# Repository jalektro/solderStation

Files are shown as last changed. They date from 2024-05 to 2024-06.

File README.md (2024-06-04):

First big schoolproject : SolderStation that is powered bij a battery(makita 18V)

In the files you can find all the schematics of the main board. There is a connection for a makita battery what can connect directly on makita 644808-8 terminal.

the display is external and is powered by a cable between display PCB and main PCB. 

the GX12 pin for soldering is wired as follows : 
-  Pin1 power from common mode choke CM2545X171B-10
-  Pin2 ground from common mode choke CM2545X171B-10
-  Pin3 output OP-AMP for temperature 
-  Pin4 connected to ground 

There are some issues in the schematics that needs to be fixed. 
The OP-AMP MCP6002-I/P VSS(pin4) and VCC(pin8)  are switched this is fixed in the schematics but not on PCB
The C-pin  of the rotary encoder PEC11R-4220F-S0012  switch is nog connected to gorund. Fixed on schematic but not on PCB

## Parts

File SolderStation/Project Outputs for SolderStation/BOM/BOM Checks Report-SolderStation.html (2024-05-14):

Date: |  | 18/04/2024
Time: |  | 18:44
Elapsed Time: |  | 00:00:00
Filename: |  | C:\AltiumFiles\SolderStation\SolderStation.BomDoc
Warnings: |  | 0
Errors: |  | 0
Fatal Errors: |  | 70
Warnings: | Count
Total | 0
Errors: | Count
Total | 0
Fatal Errors: | Count
No solutions | 70
Total | 70
No solutions
C1 , C2, C3, C4, C5, C6, C7, C8, C9, C10, C11, C17, C18, CN1, CN2, CN3, CN4, CN5, CN6, D1, D2, F1, IC1, IC2, J1, J2, J3, J4, J5, J6, J7, J8, K1, L1, L2, MAK1, R1, R2, R3, R4, R5, R6, R7, R8, R9, R10, R11, R12, R13, R14, R15, R16, R17, R18, R22, R23, R24, R25, T1, T2, T3, T4, T5, TP1, TP2, TP3, TP4, TP5, U2, ZD1

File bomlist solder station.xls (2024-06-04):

 | SOLDER STATION
Bought | Mouser No | Mfr. No | Manufacturer | Description | Qty. | Price | Total Price
Mouser | 80-C0805C103K5RAC | C0805C103K5RAC | KEMET | Multilayer Ceramic Capacitors MLCC - SMD/SMT 50V 0.01uF X7R 0805 10% | 9 | €0.03 | €0.29
Mouser | 80-C0805C104M5RACTM | C0805C104M5RAC7025 | KEMET | Multilayer Ceramic Capacitors MLCC - SMD/SMT 50V 0.1uF X7R 0805 20% | 4 | €0.02 | €0.09
Mouser | 581-TAP106M050BRW | TAP106M050BRW | KYOCERA AVX | Tantalum Capacitors - Solid Leaded 50V 10uF 20% ESR=1.6 Ohm | 3 | €2.16 | €6.48
Mouser | 581-TAP107K020CCS | TAP107K020CCS | KYOCERA AVX | Tantalum Capacitors - Solid Leaded 20V 100uF Radial ESR=600mOhms 10% | 2 | €1.65 | €3.30
Mouser | 652-PEC11R-4320K-S12 | PEC11R-4320K-S0012 | Bourns | Encoders ENCODER | 1 | €1.79 | €1.79
Mouser | 571-1033081 | 103308-1 | TE Connectivity | Headers & Wire Housings HDR VERT DOUBLE 10P low profile | 2 | €2.06 | €4.12
Mouser | 571-1658620-1 | 1658620-1 | TE Connectivity | Headers & Wire Housings MLTRY PLRZD RECPT 10 NOVO | 2 | €1.02 | €2.04
Mouser | 617-09180107001 | 09180107001 | HARTING | Flat Cables SEK CAB FLAT STD | 1 | €0.77 | €0.77
Mouser | 556-ATMEGA4809-PF | ATMEGA4809-PF | Microchip | 8-bit Microcontrollers - MCU 20MHz, 48KB, PDIP40, Ind 125C, Green | 1 | €2.88 | €2.88
Mouser | 737-ICS-640-T | ICS-640-T | Adam Tech | IC & Component Sockets 40P / .600" | 1 | €0.35 | €0.35
Mouser | 737-ICS-320-T | ICS-320-T | Adam Tech | IC & Component Sockets 20P / .300" | 1 | €0.20 | €0.20
Mouser | 576-0154003.DR | 0154003.DR | Littelfuse | Surface Mount Fuses Fuseblock w/ fuse 3A OMNI BLOK 154 | 1 | €2.08 | €2.08
Mouser | 579-MCP6002-I/P | MCP6002-I/P | Microchip | Operational Amplifiers - Op Amps Dual 1.8V 1MHz | 1 | €0.41 | €0.41
Mouser | 571-1-2199298-2 | 1-2199298-2 | TE Connectivity | IC & Component Sockets 8P DIP SKT 300 CL LADDER | 1 | €0.24 | €0.24
Mouser | 538-90151-2106 | 90151-2106 | Molex | Headers & Wire Housings C-GRID PCB CONN DR VT TN-A 6CKT | 1 | €3.02 | €3.02
Mouser | 653-G6S-2F-DC5 | G6S-2F-DC5 | Omron | Low Signal Relays - PCB Gullwing NonLatching DPDT 5VDC 140mW | 1 | €3.77 | €3.77
Mouser | 710-74479887310A | 74479887310A | Wurth Elektronik | Power Inductors - SMD WE-PMI 1008 10uH 850mA 300mOhms | 1 | €1.18 | €1.18
Mouser | 875-CM2545X171B-10 | CM2545X171B-10 | Laird Performance Materials | Common Mode Chokes / Filters 170ohms 100MHz 10A 1 Choke Thru-hole | 1 | €1.82 | €1.82
Mouser | 512-BC547B | BC547B | onsemi | Bipolar Transistors - BJT NPN 45V 100mA | 3 | €0.29 | €0.88
Mouser | 512-BC557BTF | BC557BTF | onsemi | Bipolar Transistors - BJT PNP Si Transistor Epitaxial | 1 | €0.20 | €0.20
Mouser | 844-IRF9Z34SPBF | IRF9Z34SPBF | Vishay | MOSFET P-Chan 60V 18 Amp | 1 | €1.58 | €1.58
Mouser | 595-LM7805SX/NOPB | LM7805SX/NOPB | Texas Instruments | Linear Voltage Regulators 1.5-A, 30-V, linear voltage regulator 3-DDPAK/TO-263 0 to 125 | 1 | €1.74 | €1.74
Mouser | 78-TZX5V1B | TZX5V1B-TR | Vishay | Zener Diodes 5.1 Volt 0.5W 5% | 1 | €0.11 | €0.11
Mouser | 603-AC0805FR-13100RL | AC0805FR-13100RL | YAGEO | Thick Film Resistors - SMD 100 Ohms 1/8 Wa 0805 1% AEC-Q200 | 3 | €0.01 | €0.04
Mouser | 603-AC0805FR-1010ML | AC0805FR-1010ML | YAGEO | Thick Film Resistors - SMD 10 MOhms 1/8 Watt 0805 1% AEC-Q200 | 1 | €0.01 | €0.01
Mouser | 603-AC0805FR-0710KL | AC0805FR-0710KL | YAGEO | Thick Film Resistors - SMD 10 kOhms 125mW 0805 1% AEC-Q200 Standard Power Version | 6 | €0.01 | €0.07
Mouser | 603-AC0805FR-071ML | AC0805FR-071ML | YAGEO | Thick Film Resistors - SMD 1 MOhms 125 mW 0805 1% AEC-Q200 Standard Power Version | 1 | €0.01 | €0.01
Mouser | 603-AC0805FR-075K6L | AC0805FR-075K6L | YAGEO | Thick Film Resistors - SMD 5.6k Ohms 1/8W 0805 1% AEC-Q200 Standard Power Version | 4 | €0.01 | €0.04
Mouser | 603-AC0805FR-074K7L | AC0805FR-074K7L | YAGEO | Thick Film Resistors - SMD 4.7 kOhms 125mW 0805 1% AEC-Q200 Standard Power Version | 6 | €0.01 | €0.07
Mouser | 603-AC0805FR-0718KL | AC0805FR-0718KL | YAGEO | Thick Film Resistors - SMD 18 k Ohms 125mW 0805 1% AEC-Q200 Standard Power Version | 3 | €0.02 | €0.06
Mouser | 603-AC0805FR-076K8L | AC0805FR-076K8L | YAGEO | Thick Film Resistors - SMD 6.8k Ohms 1/2W 1210 1% C-Q200 Standard Power Version | 1 | €0.01 | €0.01
Aliexpress |  |  |  | headers full set | 1 | €6.65 | €6.65
Amazon |  |  |  | connector for soldering iron GX12 4pin | 1 | €2.00 | €2.00
Aliexpress |  |  |  | DC-DC step down convertor | 1 | €4.13 | €4.13
Aliexpress |  |  |  | TM1637 Dip-20 IC | 1 | €0.40 | €0.40
TME |  |  |  | 7seg display | 1 | €1.70 | €1.70
 |  |  |  |  |  | Total price | €54.53

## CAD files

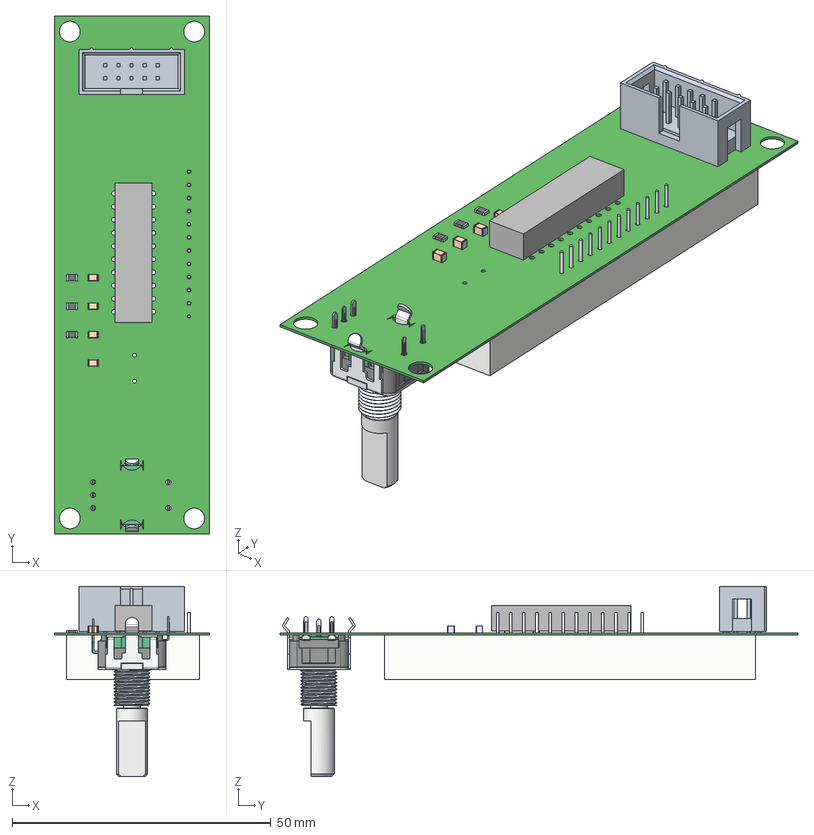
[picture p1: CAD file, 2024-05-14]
DisplaySolderStation/Display.step
30.0 x 100.0 x 36.7 mm
term1 x 3
term2 x 3
7segment v1
c-1634688-10-c-3d
Extruded
Bourns

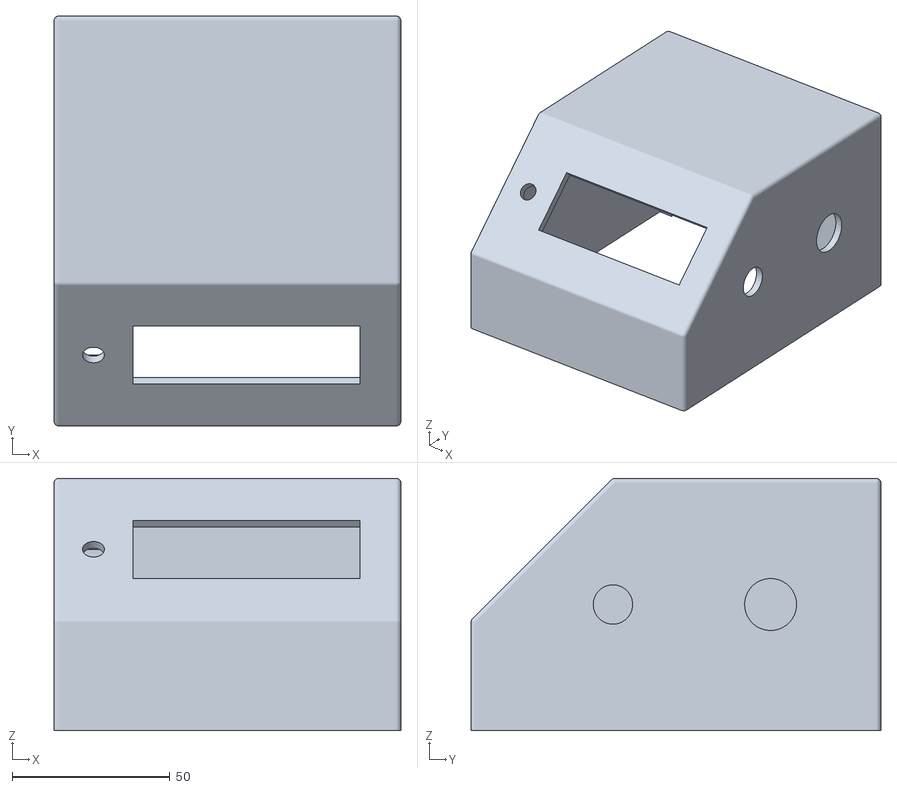
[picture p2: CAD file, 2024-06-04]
SolderStation/casingtop v6.stl
110.0 x 130.0 x 80.0

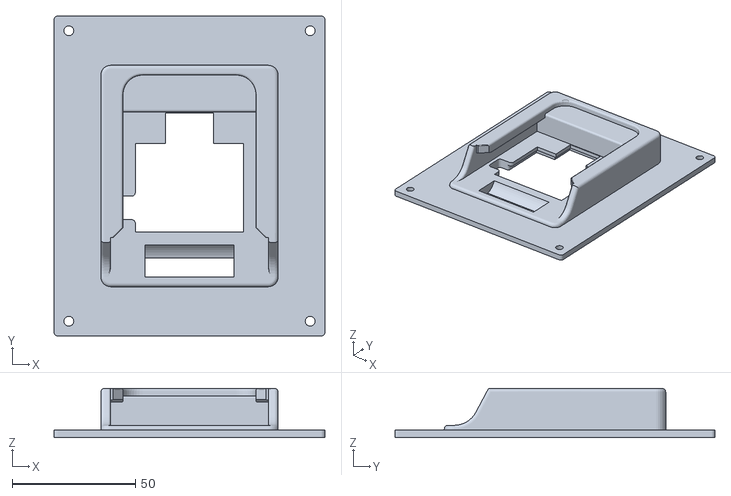
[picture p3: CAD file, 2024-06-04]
SolderStation/bottomplate v4.stl
110.0 x 130.0 x 20.0

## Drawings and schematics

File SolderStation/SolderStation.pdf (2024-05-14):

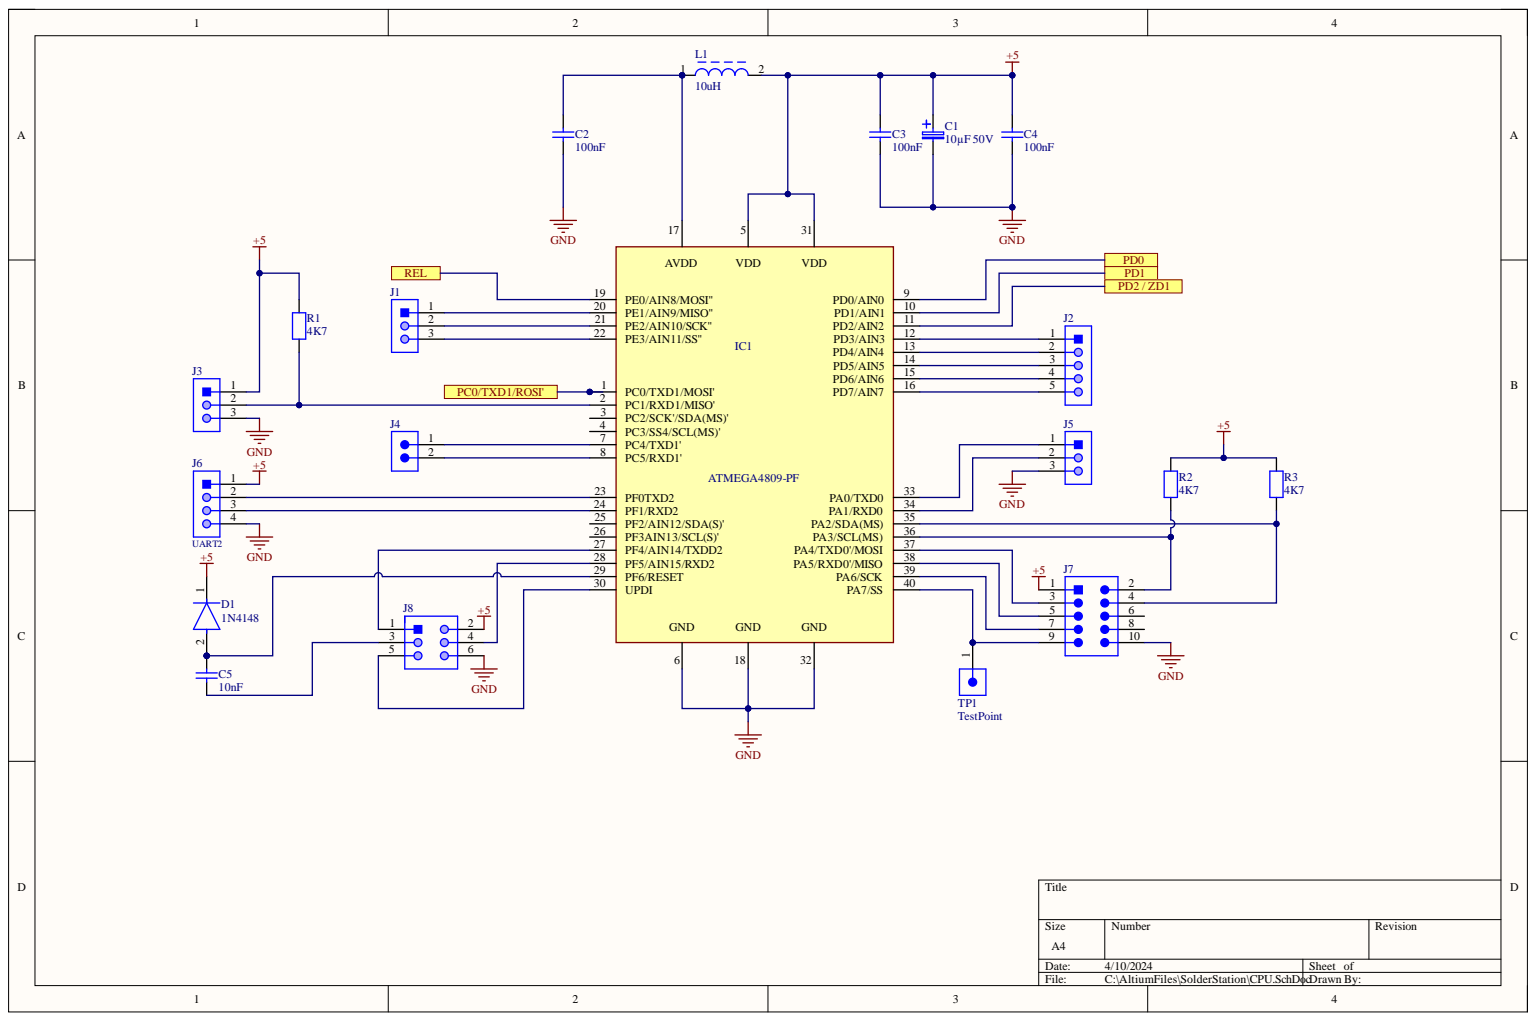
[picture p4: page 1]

2 | PE2/AIN10/SCK" 21 | | J2
3 | PE3/AIN11/SS" 22 | 1

PC0/TXD1/MOSI' 1 | 2

PF5/AIN15/RXD2 28
PF6/RESET 29 UPDI 30

5 | | 6 | 18 | 32

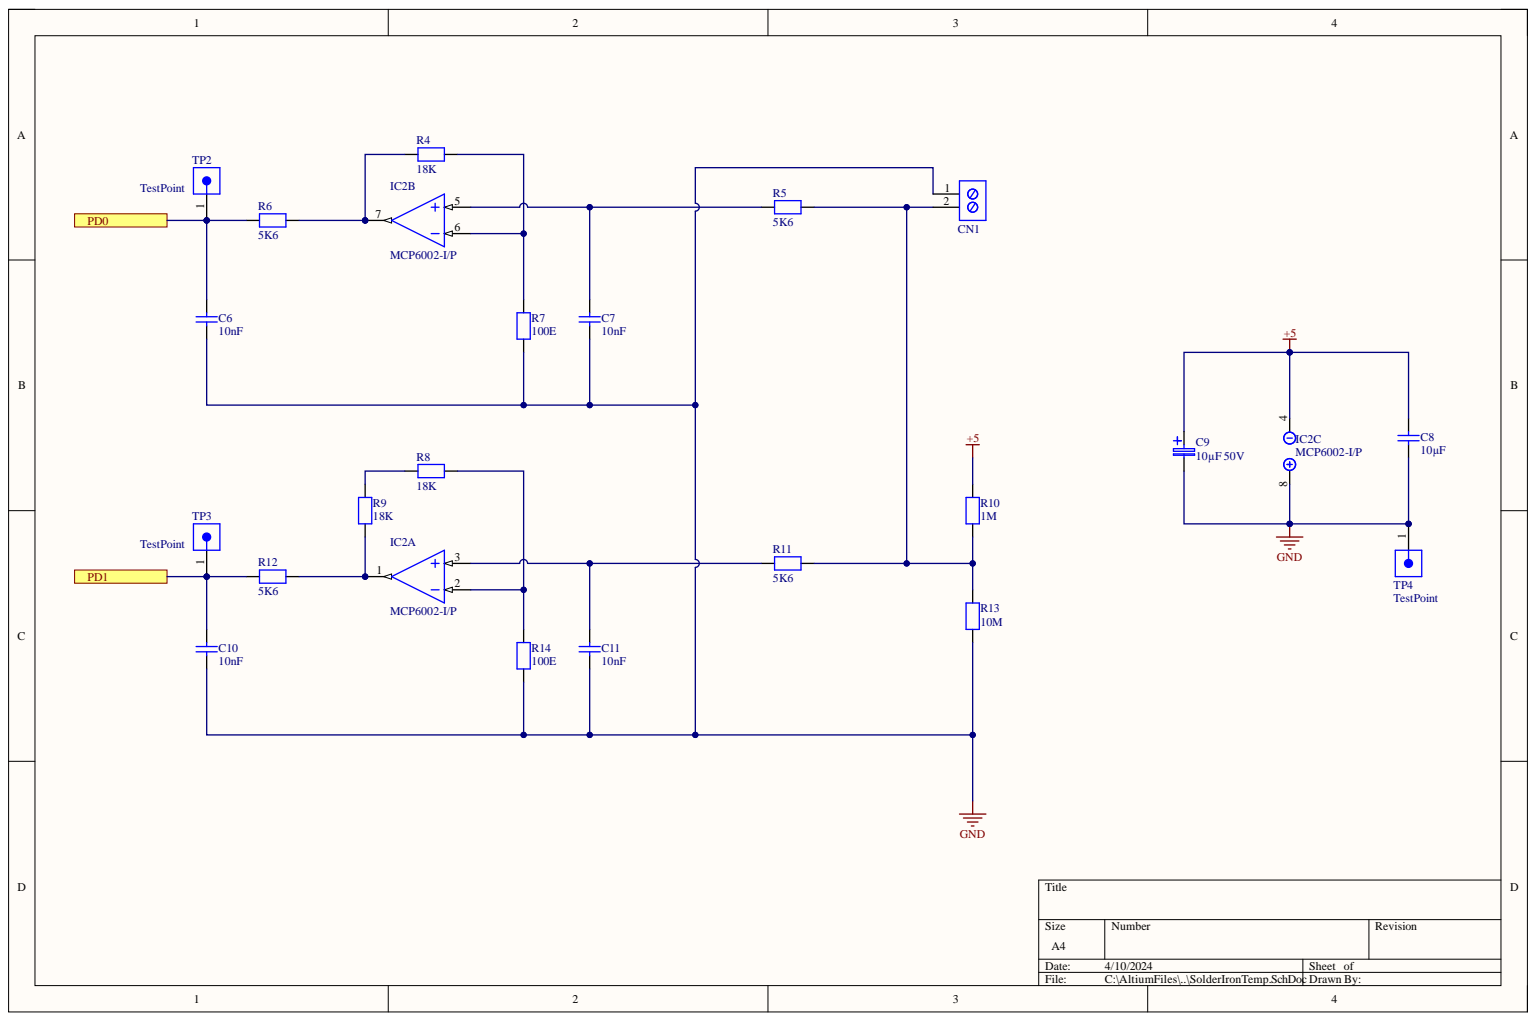
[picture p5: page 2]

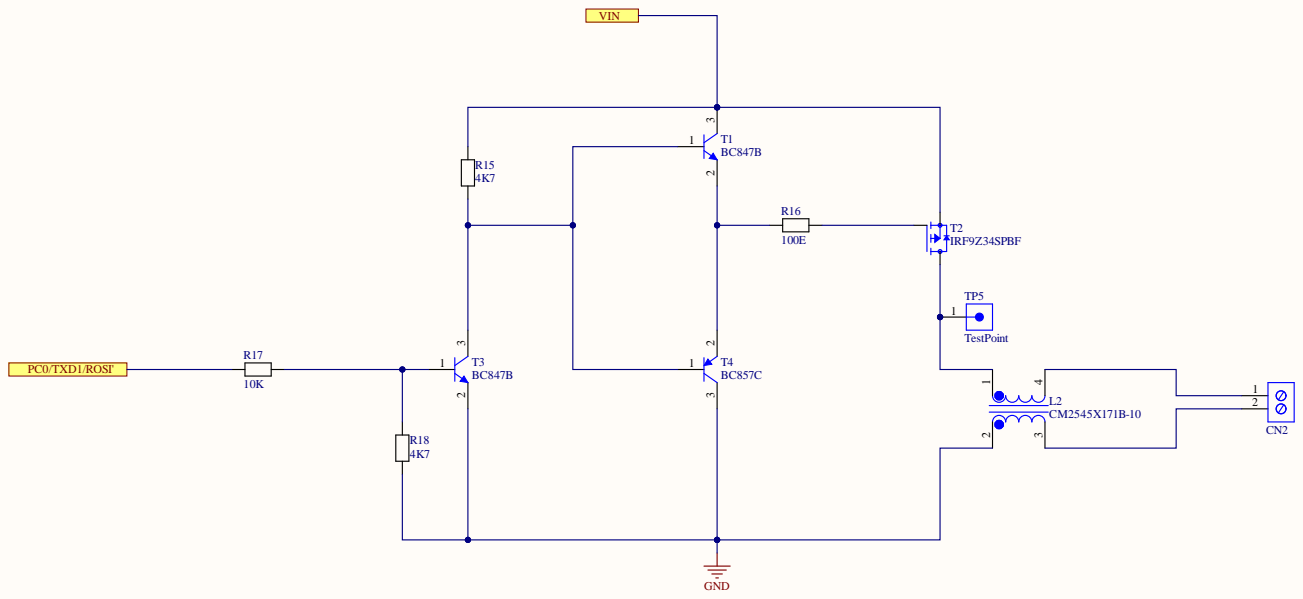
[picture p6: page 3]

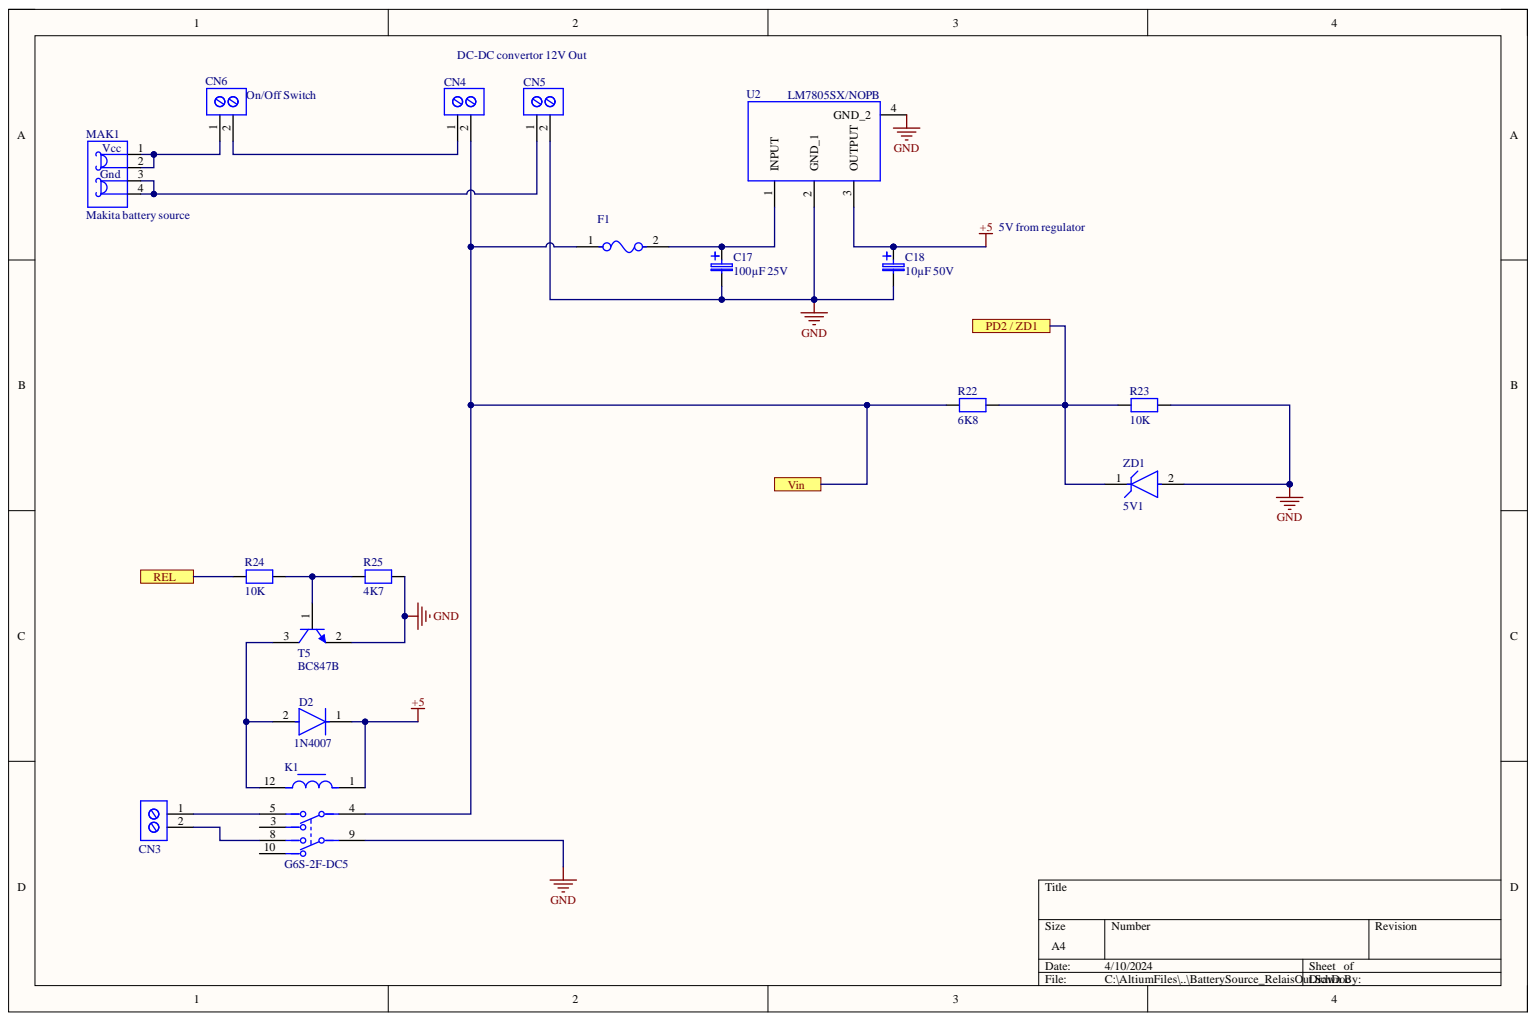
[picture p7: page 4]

DC-DC convertor 12V Out

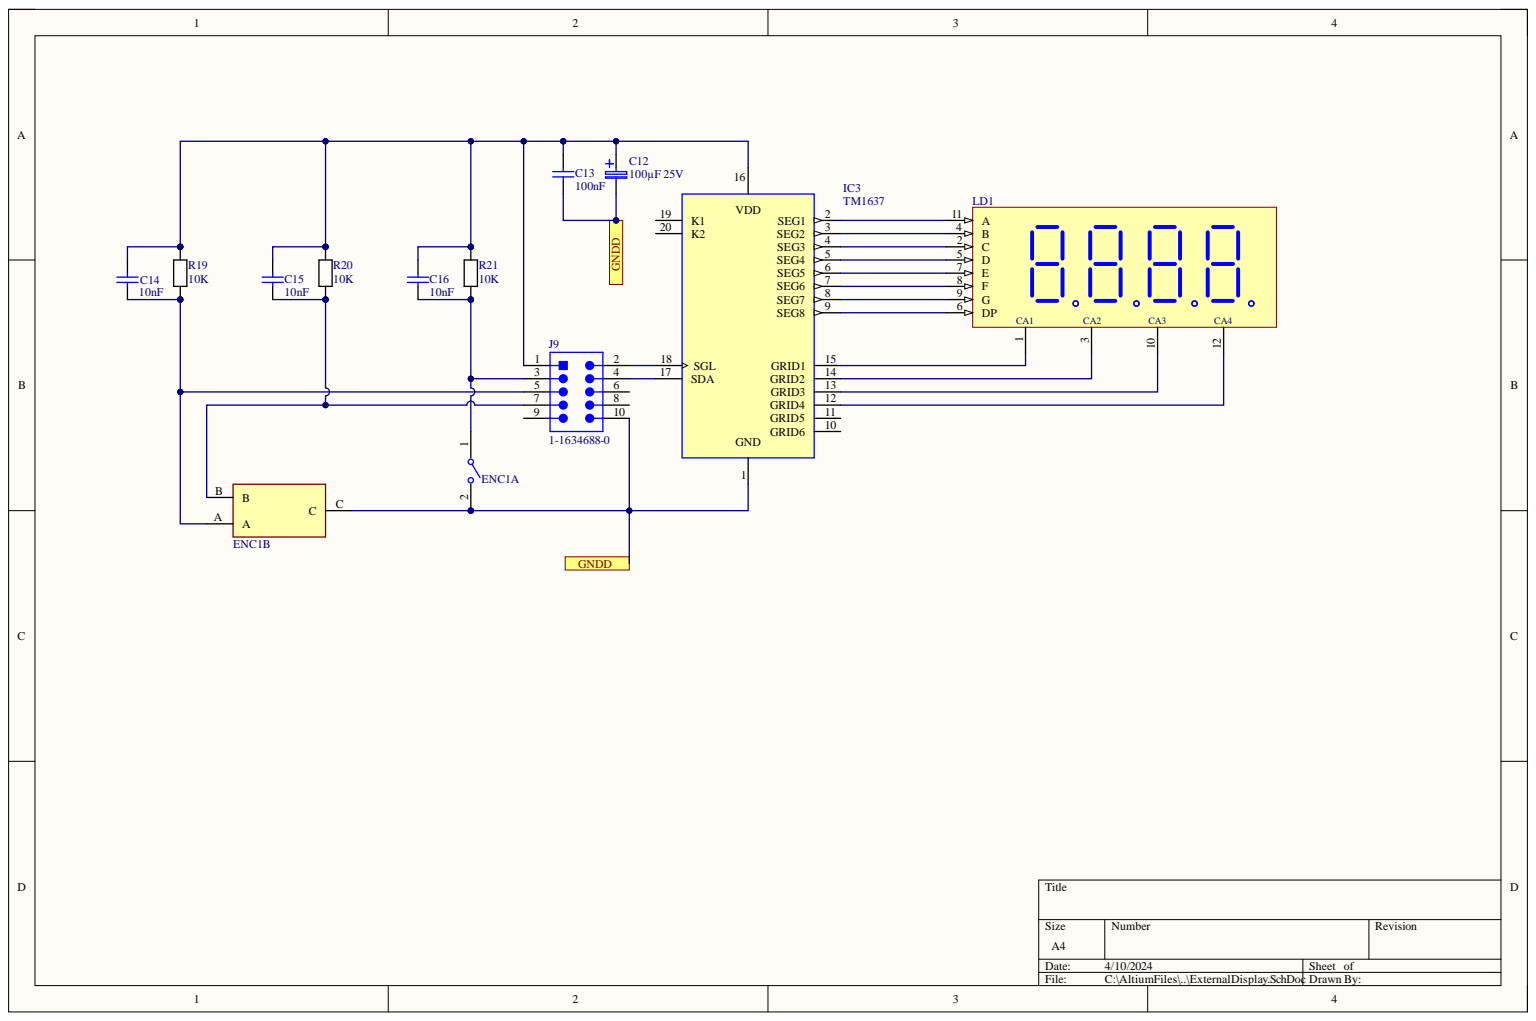
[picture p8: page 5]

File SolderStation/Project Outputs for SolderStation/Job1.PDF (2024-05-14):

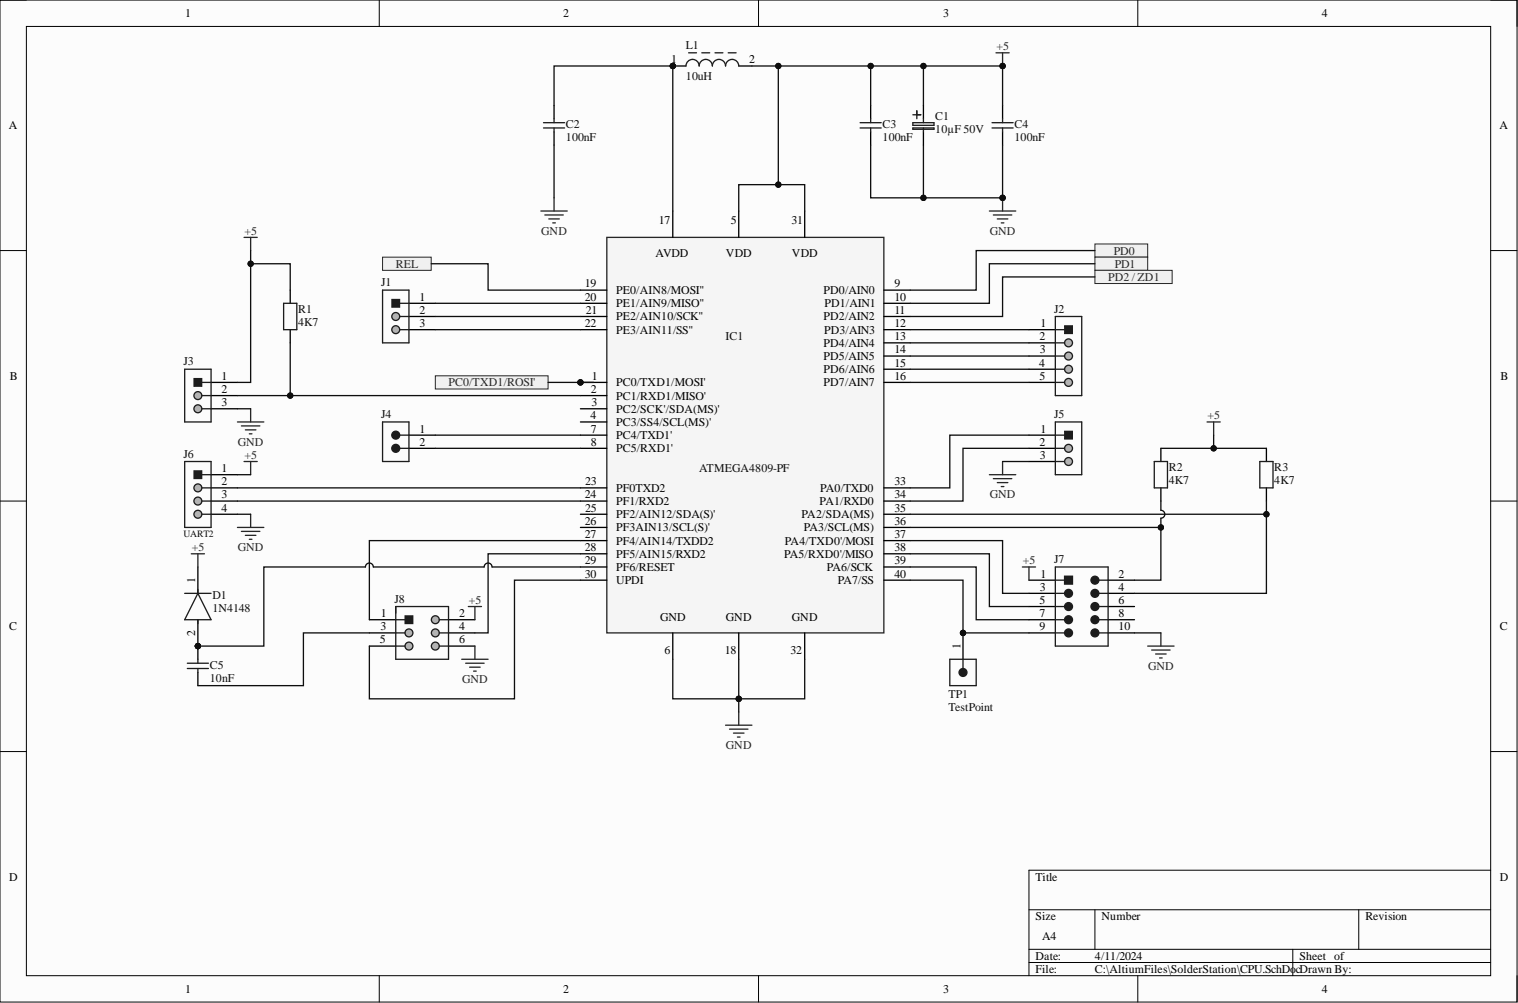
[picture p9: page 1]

2 | PE2/AIN10/SCK" 21 | | J2
3 | PE3/AIN11/SS" 22 | 1

PC0/TXD1/MOSI' 1 | 2

PF5/AIN15/RXD2 28
PF6/RESET 29 UPDI 30

5 | | 6 | 18 | 32

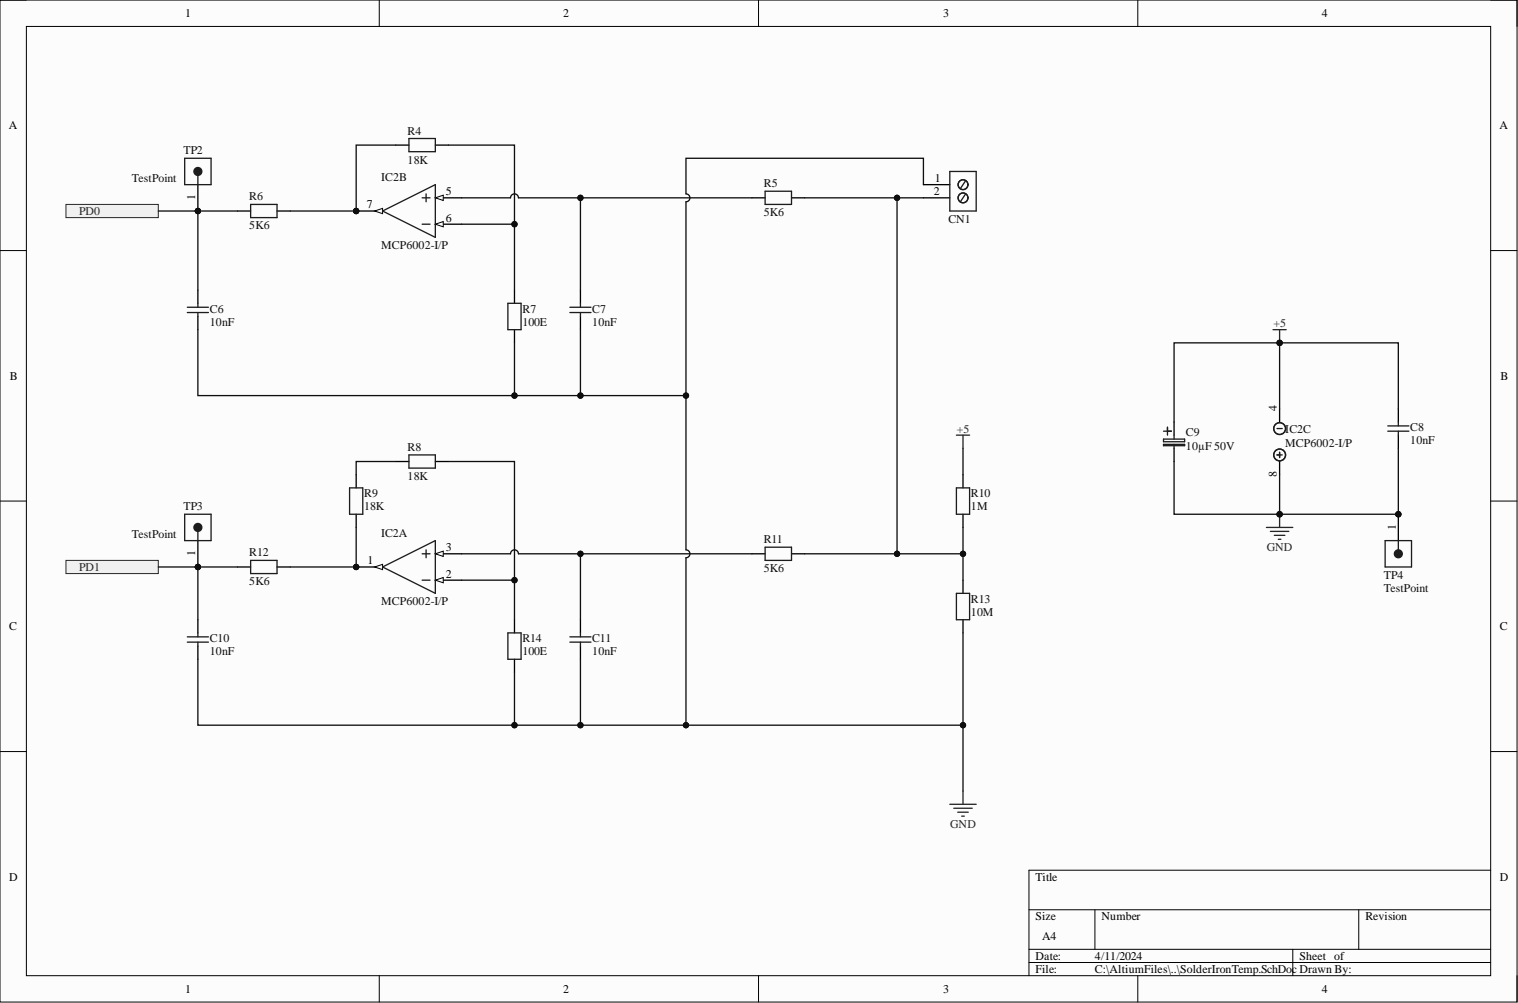
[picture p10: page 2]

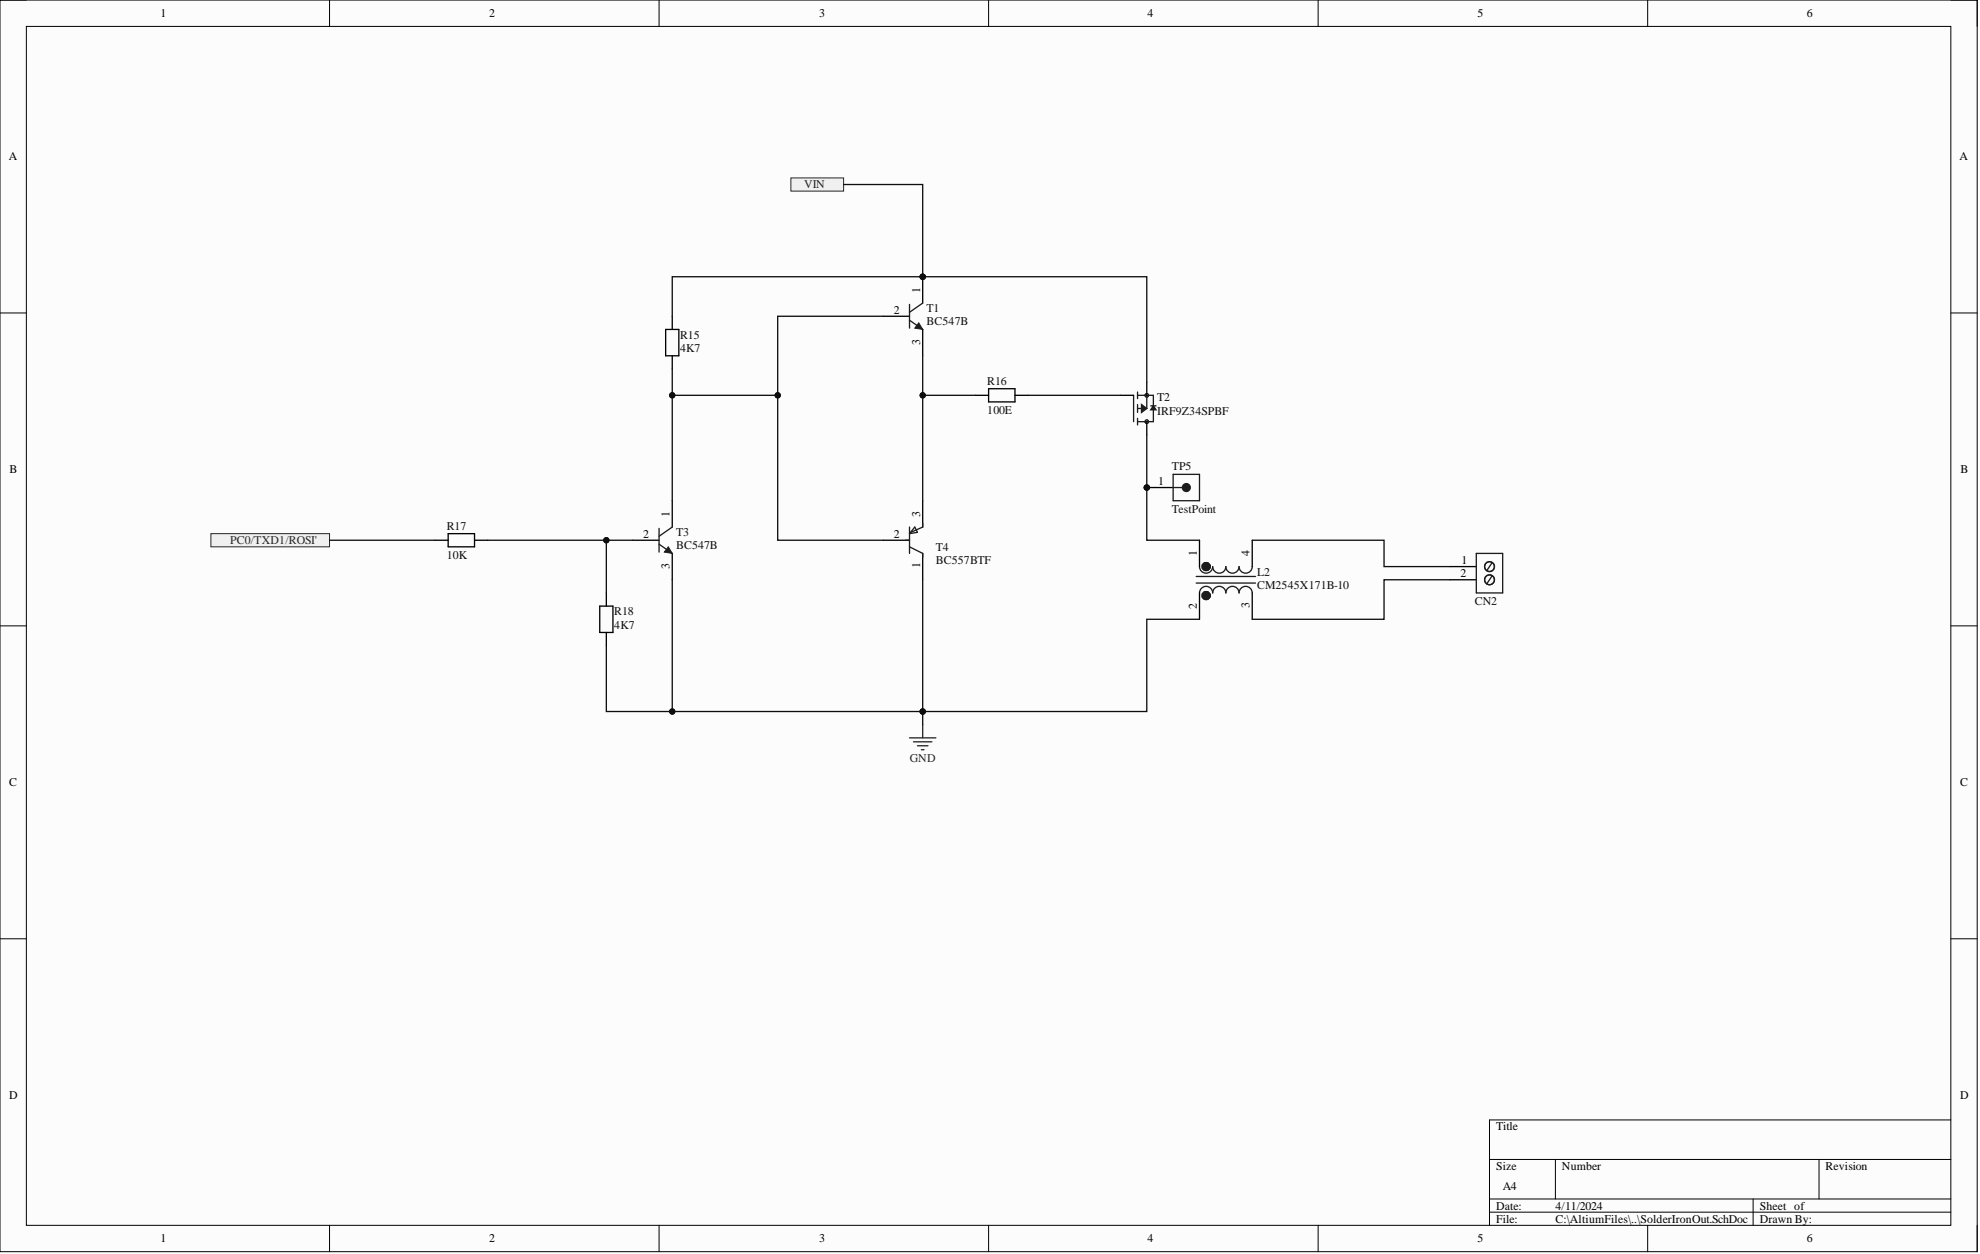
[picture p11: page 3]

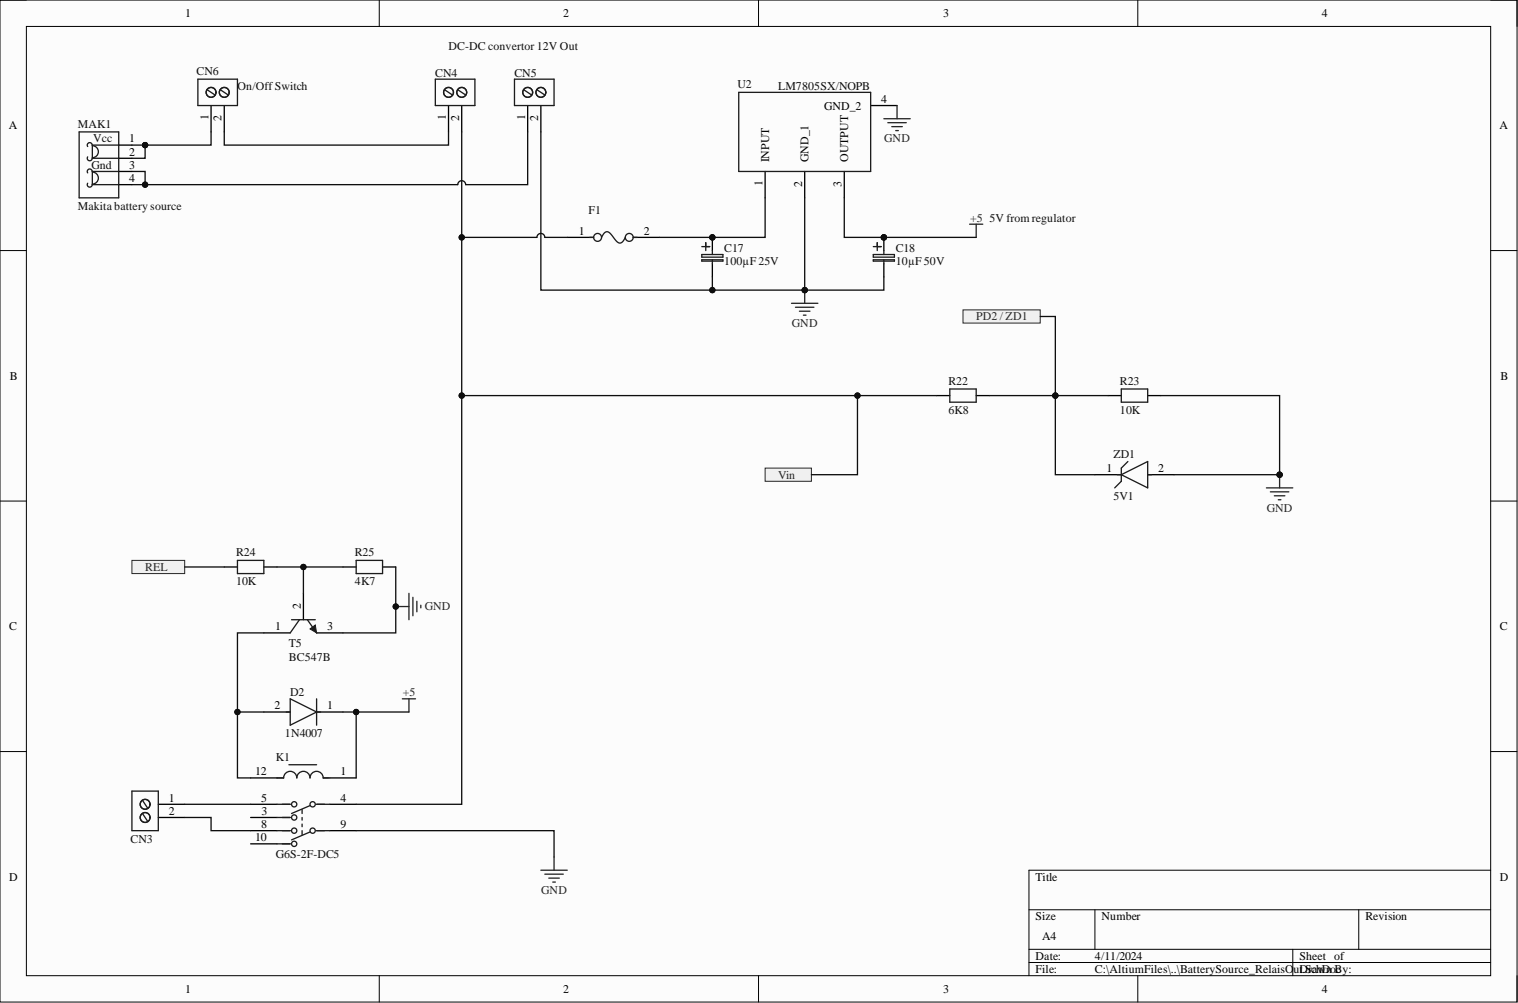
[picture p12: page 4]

DC-DC convertor 12V Out

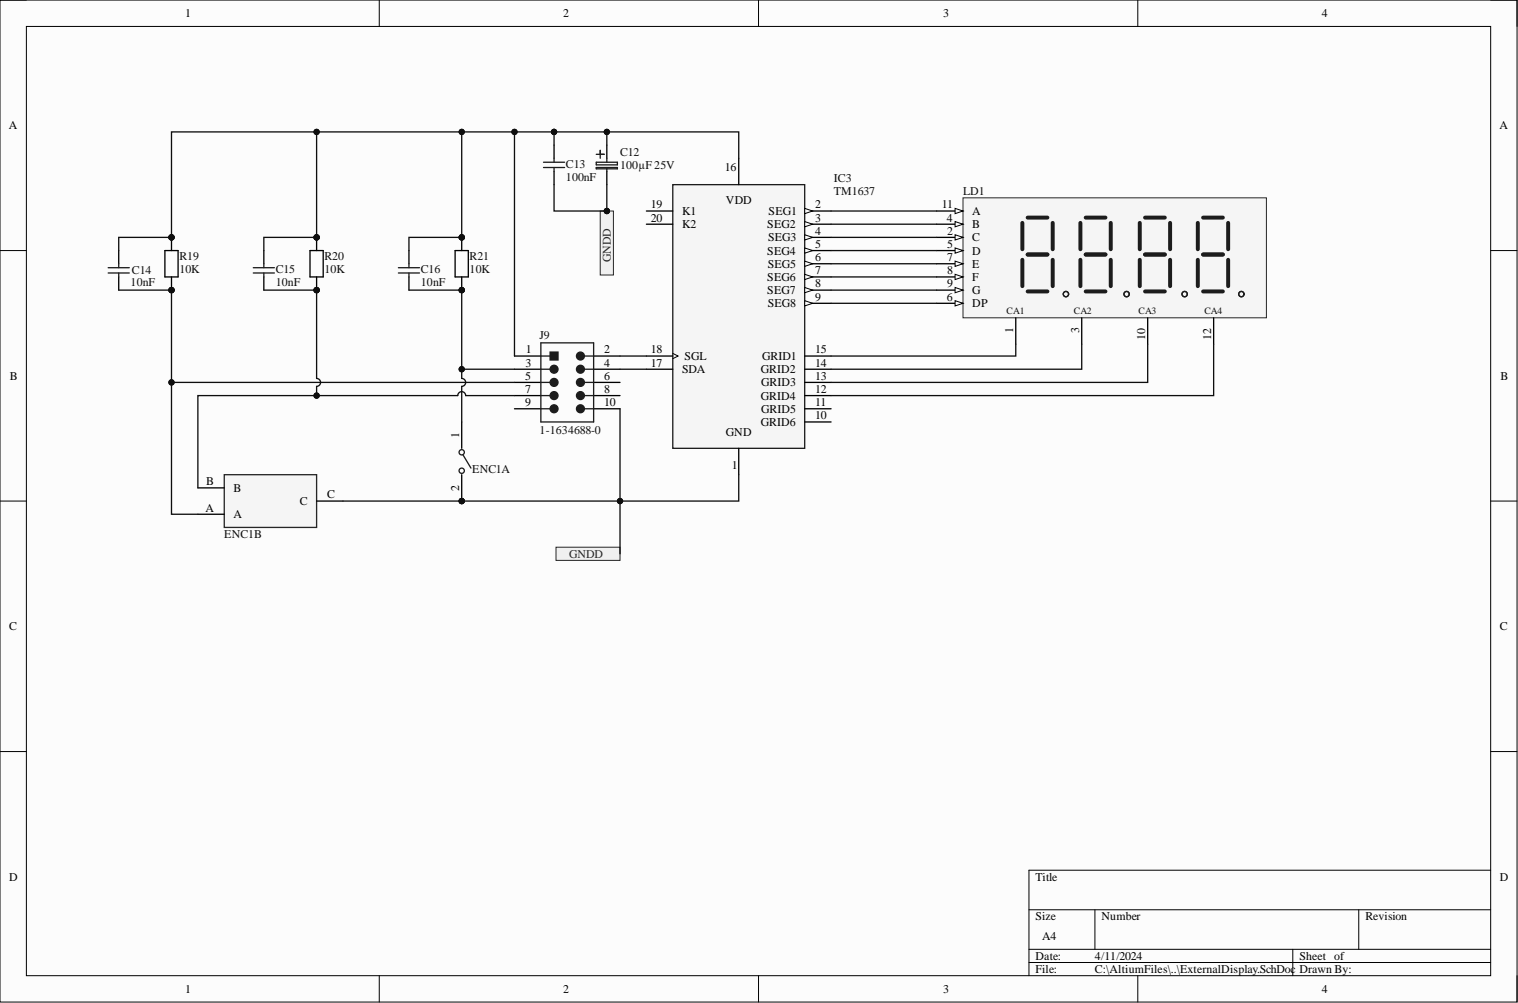
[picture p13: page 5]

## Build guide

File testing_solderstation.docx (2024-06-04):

Testing solderstation

Eerste test:

-meting tussen vcc en ground : 16K

- 12 volt op main bord CN4 en CN5.

Metingen op main board gedaan op cruciale plaatsen, geen bemerkingen

5 Volt op display geplaatst, GND vergeten op pin C van de encoder, brug geplaatst op de encoder tussen pin C en pin A. verder geen problemen gemeten met 5Volt

Fout gevonden bij plaatsen van op-amp. Hersteld door brug te plaatsen.

Verdere testen dienen nog te gebeuren.

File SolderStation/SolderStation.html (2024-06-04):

Reporting Options

# File in Newer Format

Date | : | 2/06/2024
Time | : | 9:55:35
Filename | : | C:\AltiumFiles\SolderStation\SolderStation.PrjPcb

Version | Warning

Release 23.10

CAUTION - This project contains rules defined using the Constraint Manager. You are seeing this message for two possible reasons. Firstly, this is an older version of the software that does not support this feature, in which case design rules will fall back to being presented as standard, query-based rules. If you save the PCB project in this older version of Altium Designer, all Constraint Manager data structure information will be lost. Secondly, if this software version does support the feature, then you currently don't have the level of Altium Designer Software Subscription (Pro/Enterprise) to be able to edit constraints using the Constraint Manager, in which case it will present rules in view only mode.

This file was generated by a later version of the software

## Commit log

2024-05-14 first commit to push full project to github
    [BatterySource_RelaisOut.SchDoc, CPU.SchDoc, Display.PcbDoc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]
2024-05-26 added bomlist excel file
    [bomlist solder station.xls]
2024-06-04 update schematics after testing the PCB
    [Display.SchDoc, SolderIronOut.SchDoc, SolderIronTemp.SchDoc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]
